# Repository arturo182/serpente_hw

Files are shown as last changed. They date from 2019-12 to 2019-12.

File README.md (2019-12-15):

# Serpente

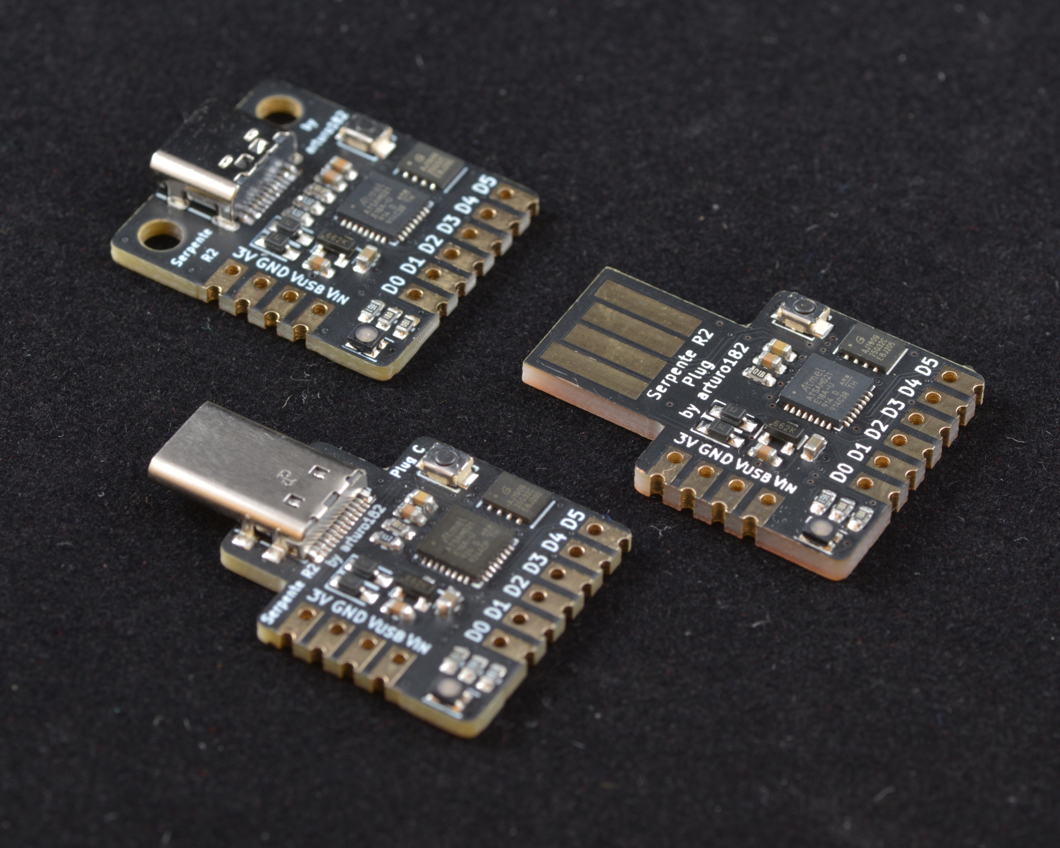
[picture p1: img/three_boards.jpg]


A tiny and cheap CircuitPython development board, perfect for quick projects and prototyping!

Comes in three versions: Female USB Type-C, Male USB Type-C, and bare PCB USB A plug.

# Technical details

- ATSAMD21E18A 32-bit Cortex-M0+ running at 48MHz
- 256KB flash and 32KB RAM
- 4MB Flash for storing files and CircuitPython code
- 6 highly customizable GPIOs
- 250mA LDO
- 3.3V logic and power
- Powered either from USB or external source
- User-controlled RGB LED
- Breadboardable headers
- Castellated edges, can be used as a module
- Mounting holes on the Female Type-C board

# Documentation

For more information visit https://serpente.solder.party/

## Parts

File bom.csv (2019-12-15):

Reference | Quantity | Value | Footprint | Datasheet | LCSC
C2 | 1 | 0.1uF | Capacitor_SMD:C_0603_1608Metric | ~
C3 | 1 | 10uF | Capacitor_SMD:C_0603_1608Metric | ~
C4 C1 | 2 | 1uF | Capacitor_SMD:C_0603_1608Metric | ~
D1 D2 | 2 | D_Schottky_Small | Diode_SMD:D_SOD-323_HandSoldering | ~ | C114023
D3 | 1 | LED_RBAG | LED_SMD:LED_Cree-PLCC4_2x2mm_CW | ~ | C108793
J1 | 1 | USB_C_Receptacle_USB2.0 | Connector_USB_Extra:USB_C_Receptacle_GT-USB-7010 | https://www.usb.org/sites/default/files/documents/usb_type-c.zip | C319148
J2 | 1 | Conn_Power | Connector_PinHeader_2.54mm_Extra:PinHeader_1x04_P2.54mm_Vertical_Castellated | ~
J3 | 1 | Conn_GPIO | Connector_PinHeader_2.54mm_Extra:PinHeader_1x06_P2.54mm_Vertical_Castellated | ~
R1 | 1 | 360R | Resistor_SMD:R_0603_1608Metric | ~
R2 R3 | 2 | 150R | Resistor_SMD:R_0603_1608Metric | ~
R4 R5 | 2 | 5.1K | Resistor_SMD:R_0603_1608Metric | ~
R6 | 1 | 1K | Resistor_SMD:R_0603_1608Metric | ~
SW1 | 1 | SW_RESET | Button_Switch_SMD:SW_SPST_B3U-1000P-B | ~ | C128937
TP1 | 1 | TP_SWCLK | TestPoint:TestPoint_Pad_D1.0mm | ~
TP2 | 1 | TP_SWDIO | TestPoint:TestPoint_Pad_D1.0mm | ~
TP3 | 1 | TP_VDD | TestPoint:TestPoint_Pad_D1.0mm | ~
TP4 | 1 | TP_GND | TestPoint:TestPoint_Pad_D1.0mm | ~
TP5 | 1 | TP_USB_D- | TestPoint:TestPoint_Pad_D1.0mm | ~
TP6 | 1 | TP_USB_D+ | TestPoint:TestPoint_Pad_D1.0mm | ~
TP7 | 1 | TP_RESET | TestPoint:TestPoint_Pad_D1.0mm | ~
U1 | 1 | GD25Q32CNIGR | Package_SON_Extra:USON-8_3x4mm_P0.8mm
U2 | 1 | MCP1700-3302E_SOT23 | Package_TO_SOT_SMD:SOT-23 | http://ww1.microchip.com/downloads/en/DeviceDoc/20001826D.pdf | C83932
U3 | 1 | ATSAMD21E18A | Package_DFN_QFN:QFN-32-1EP_5x5mm_P0.5mm_EP3.6x3.6mm

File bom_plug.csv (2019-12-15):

Reference | Quantity | Value | Footprint | Datasheet
C2 | 1 | 0.1uF | Capacitor_SMD:C_0603_1608Metric | ~
C3 | 1 | 10uF | Capacitor_SMD:C_0603_1608Metric | ~
C4 C1 | 2 | 1uF | Capacitor_SMD:C_0603_1608Metric | ~
D2 D1 | 2 | D_Schottky_Small | Diode_SMD:D_SOD-323_HandSoldering | ~
D3 | 1 | LED_RBAG | LED_SMD:LED_Cree-PLCC4_2x2mm_CW | ~
J1 | 1 | USB_A | Connector_USB_Extra:USB_A_Plug_PCB | ~
J2 | 1 | Conn_Power | Connector_PinHeader_2.54mm_Extra:PinHeader_1x04_P2.54mm_Vertical_Castellated | ~
J3 | 1 | Conn_GPIO | Connector_PinHeader_2.54mm_Extra:PinHeader_1x06_P2.54mm_Vertical_Castellated | ~
R1 | 1 | 360R | Resistor_SMD:R_0603_1608Metric | ~
R3 R2 | 2 | 150R | Resistor_SMD:R_0603_1608Metric | ~
R6 | 1 | 1K | Resistor_SMD:R_0603_1608Metric | ~
SW1 | 1 | SW_RESET | Button_Switch_SMD:SW_SPST_B3U-1000P-B | ~
TP1 | 1 | TP_SWCLK | TestPoint:TestPoint_Pad_D1.0mm | ~
TP2 | 1 | TP_SWDIO | TestPoint:TestPoint_Pad_D1.0mm | ~
TP3 | 1 | TP_VDD | TestPoint:TestPoint_Pad_D1.0mm | ~
TP4 | 1 | TP_GND | TestPoint:TestPoint_Pad_D1.0mm | ~
TP5 | 1 | TP_USB_D- | TestPoint:TestPoint_Pad_D1.0mm | ~
TP6 | 1 | TP_USB_D+ | TestPoint:TestPoint_Pad_D1.0mm | ~
TP7 | 1 | TP_RESET | TestPoint:TestPoint_Pad_D1.0mm | ~
U1 | 1 | GD25Q32CNIGR | Package_SON_Extra:USON-8_3x4mm_P0.8mm
U2 | 1 | MCP1700-3302E_SOT23 | Package_TO_SOT_SMD:SOT-23 | http://ww1.microchip.com/downloads/en/DeviceDoc/20001826D.pdf
U3 | 1 | ATSAMD21E18A | Package_DFN_QFN:QFN-32-1EP_5x5mm_P0.5mm_EP3.6x3.6mm

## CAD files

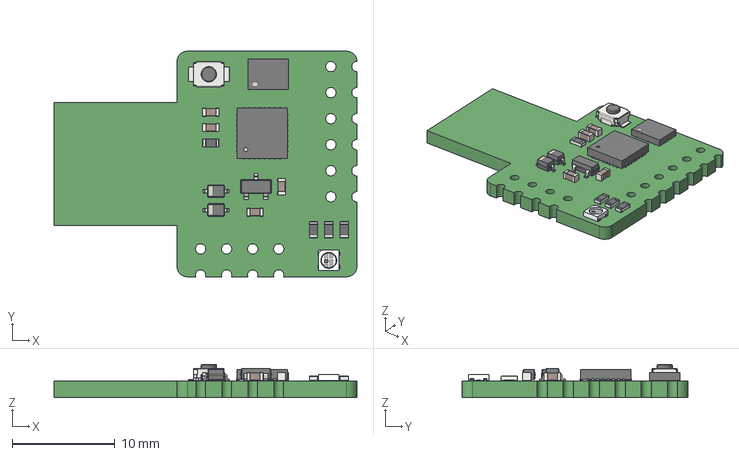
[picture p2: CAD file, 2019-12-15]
serpente_plug.step
29.6 x 22.0 x 3.24 mm

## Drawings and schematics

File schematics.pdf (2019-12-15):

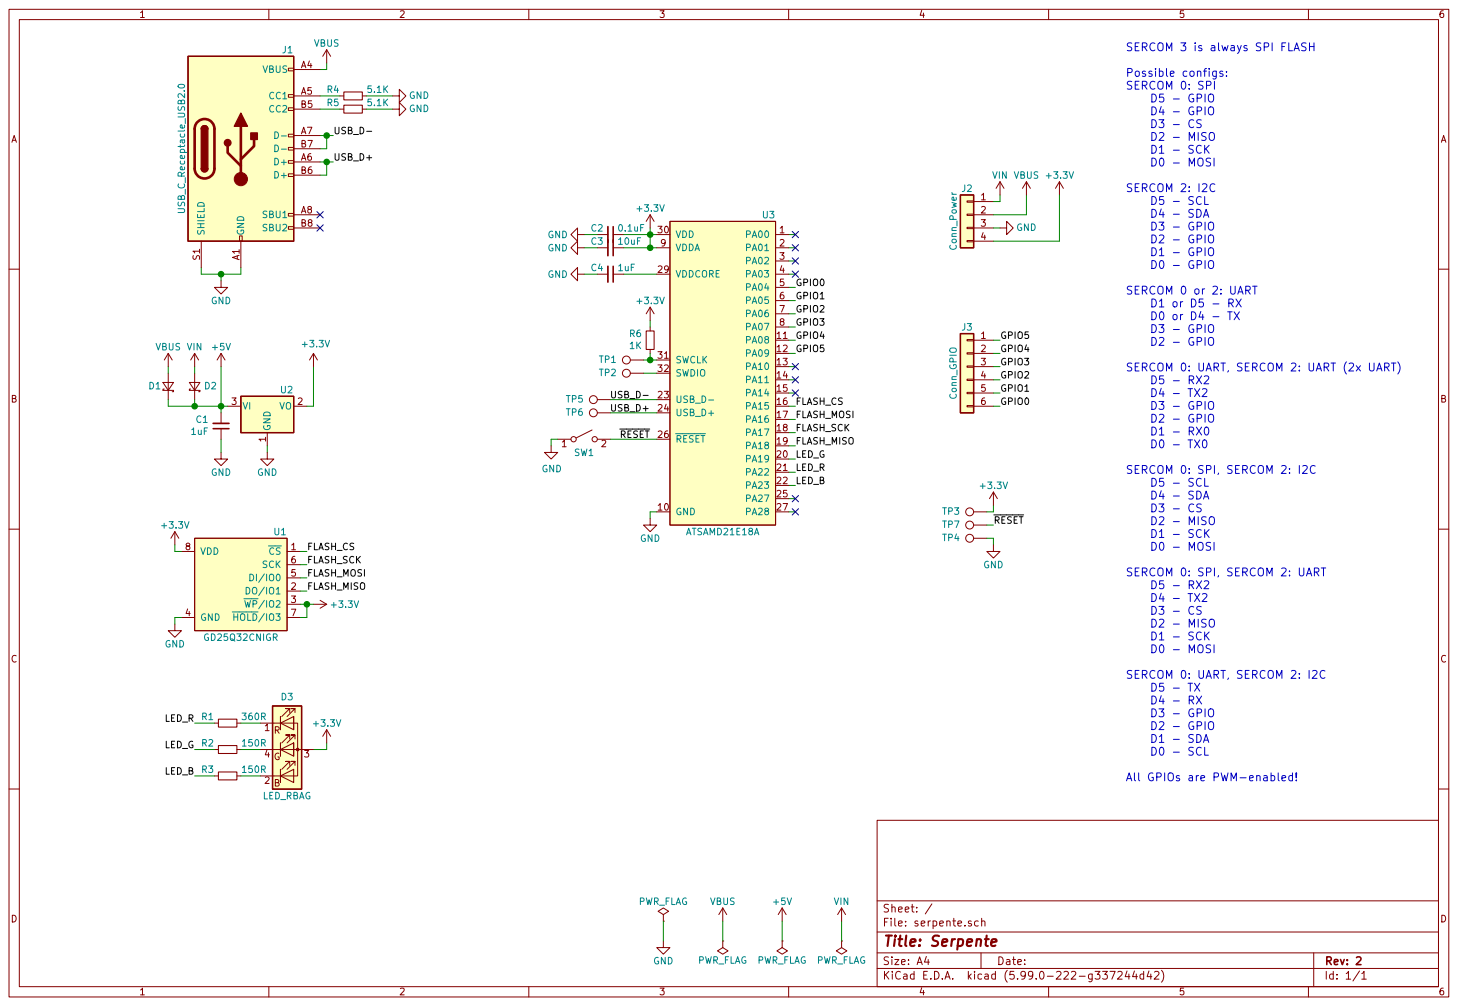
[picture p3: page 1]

All GPIOs are PWM-enabled! +5V

File: serpente.sch Sheet: /
Id: 1/1 Title: Serpente

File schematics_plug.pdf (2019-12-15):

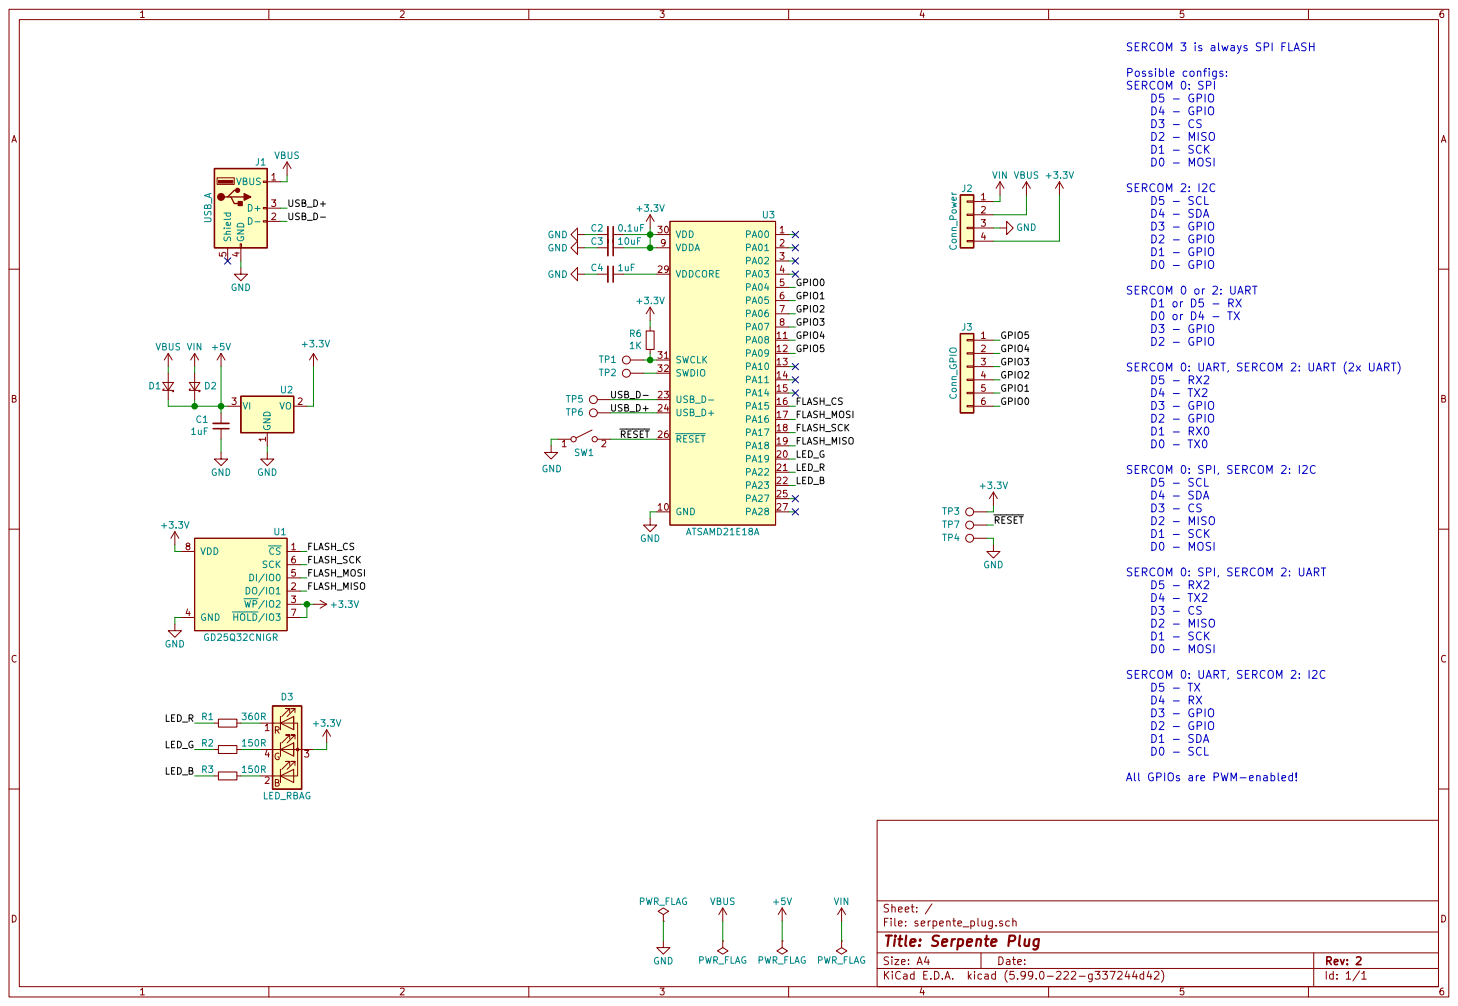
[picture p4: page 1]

SERCOM 3 is always SPI FLASH

File: serpente_plug.sch Sheet: /
Id: 1/1 Title: Serpente Plug

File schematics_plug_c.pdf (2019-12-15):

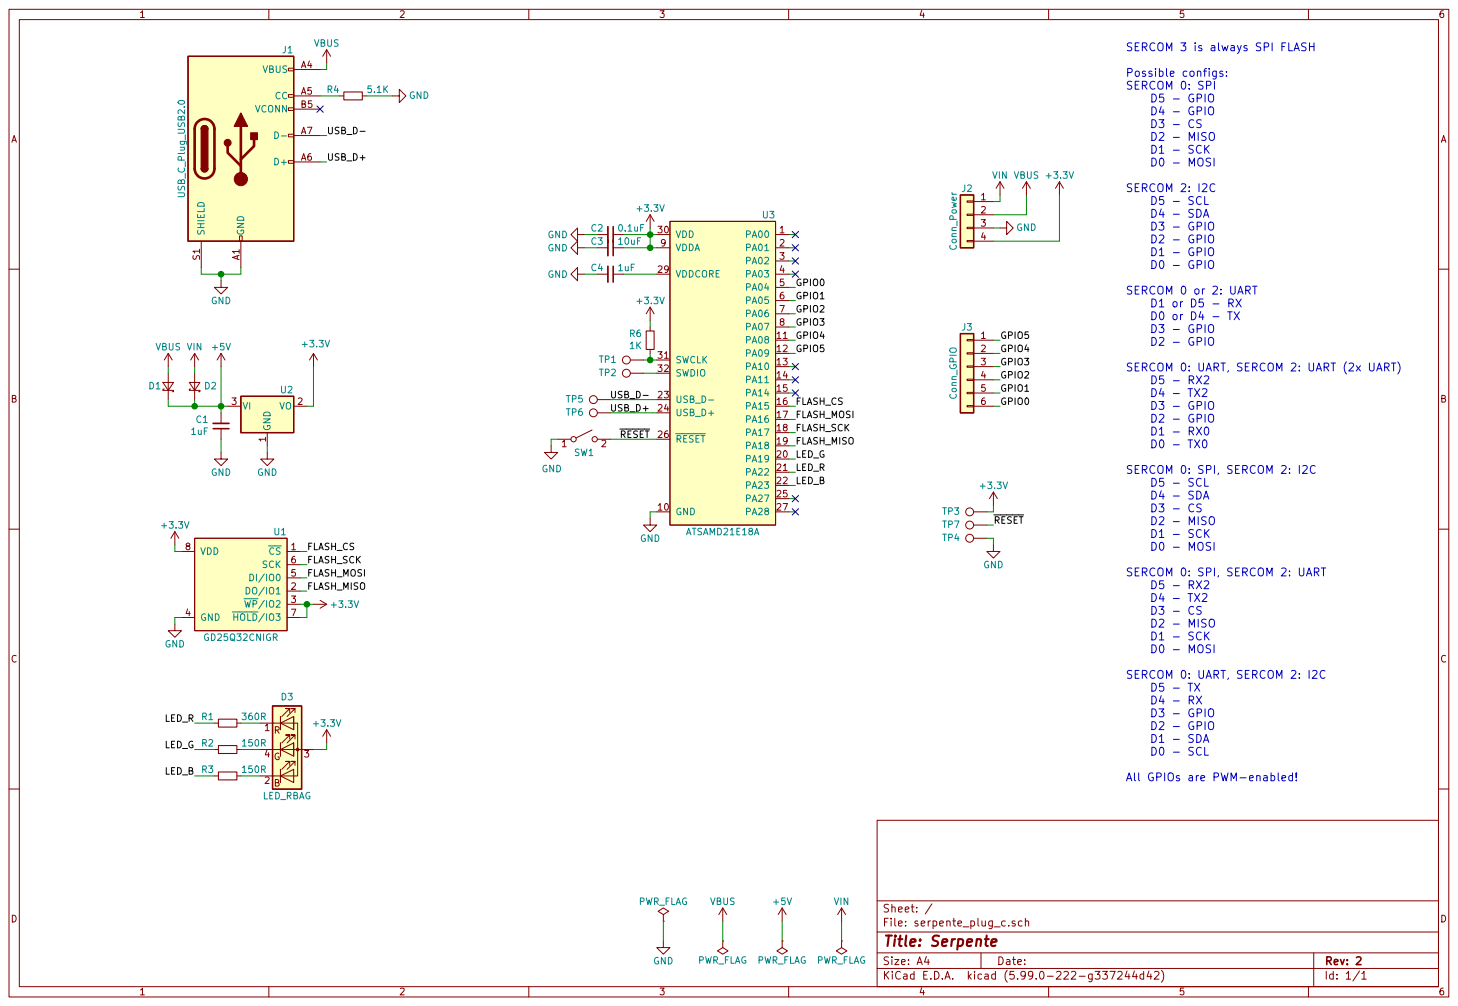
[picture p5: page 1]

All GPIOs are PWM-enabled! +5V

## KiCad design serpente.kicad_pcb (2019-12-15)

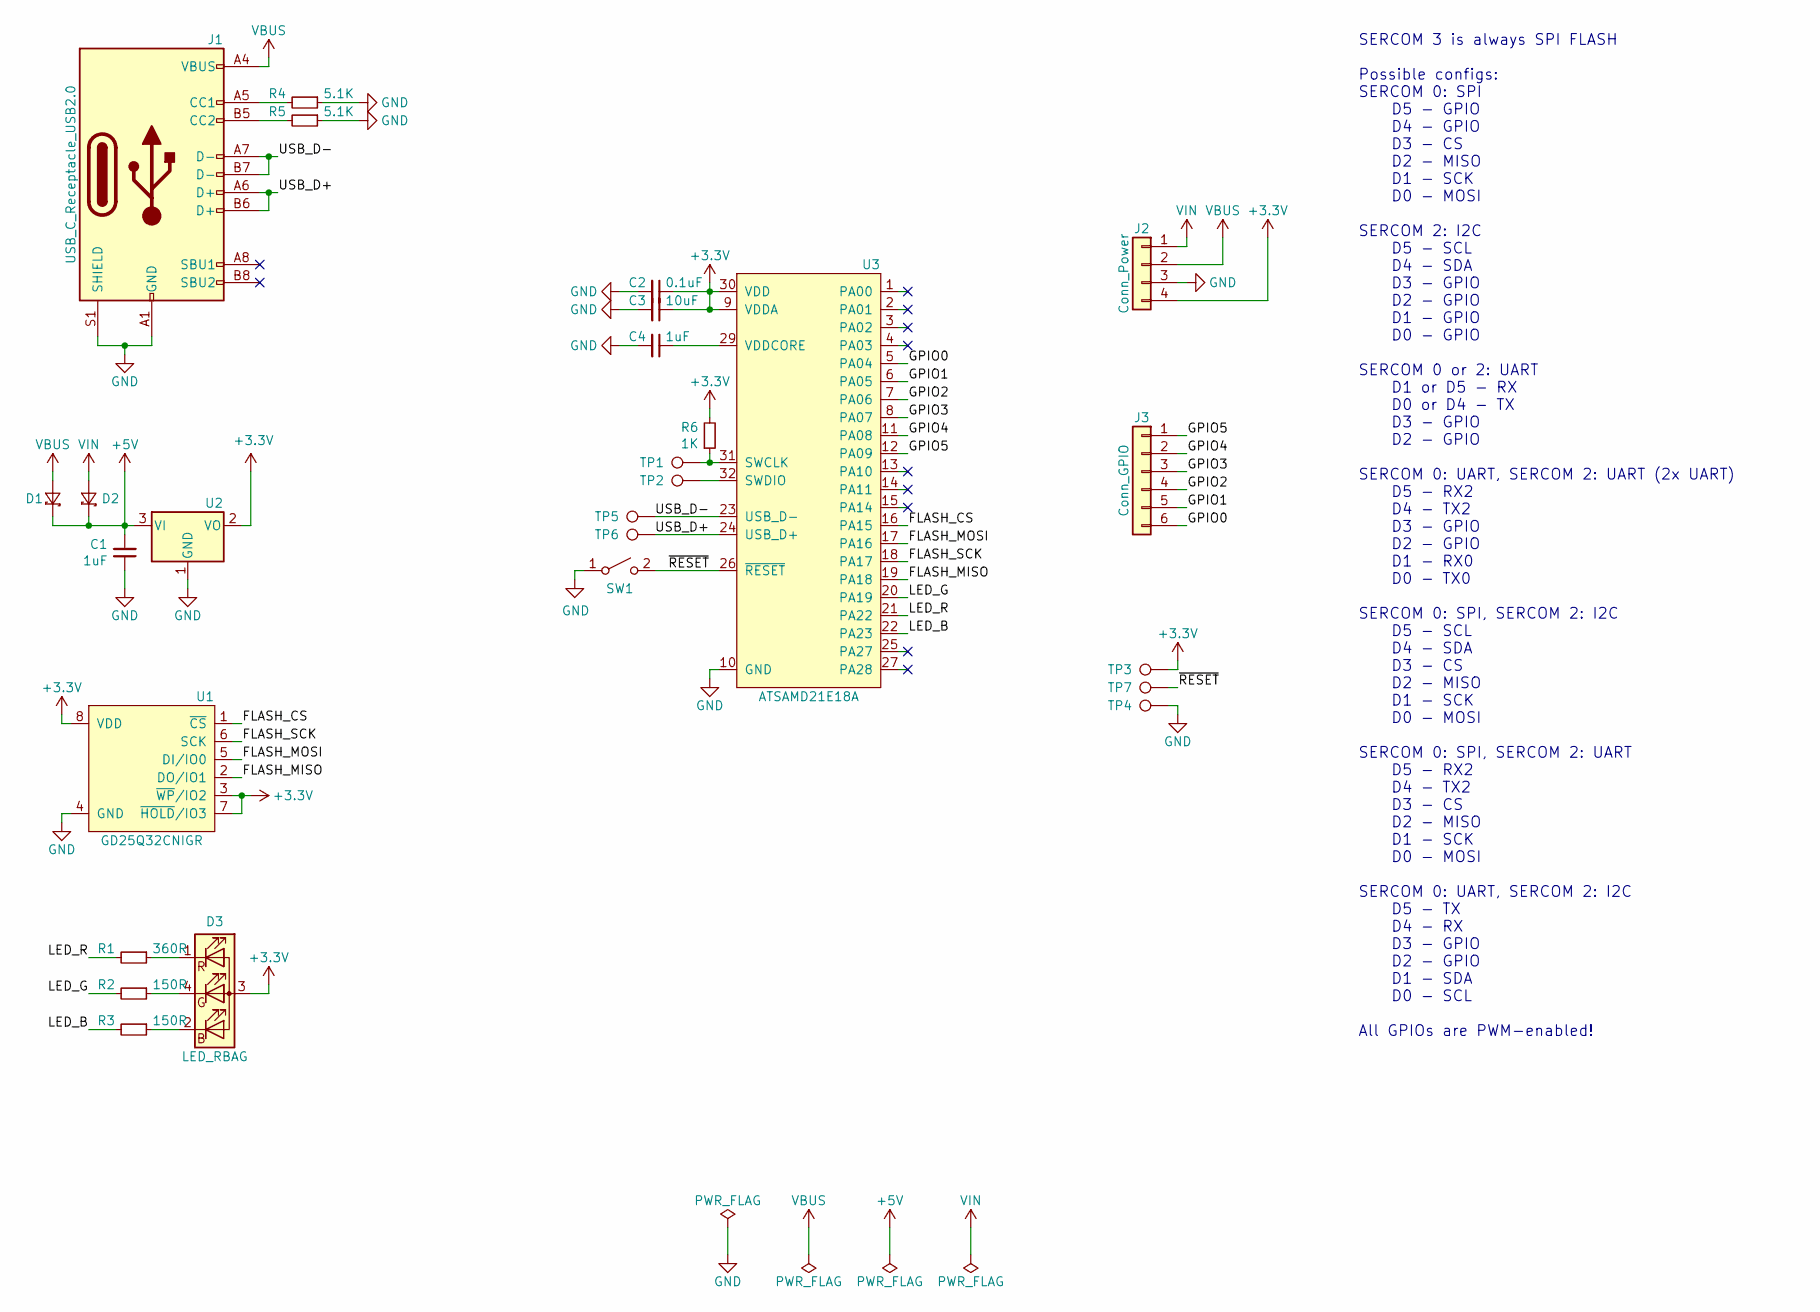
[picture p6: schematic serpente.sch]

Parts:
C1, C4: 1uF; C_0603_1608Metric
C2: 0.1uF; C_0603_1608Metric
C3: 10uF; C_0603_1608Metric
D1, D2: D_Schottky_Small; D_SOD-323_HandSoldering; LCSC C114023
D3: LED_RBAG; LED_Cree-PLCC4_2x2mm_CW; LCSC C108793
J1: USB_C_Receptacle_USB2.0; USB_C_Receptacle_GT-USB-7010; LCSC C319148
J2: Conn_Power; PinHeader_1x04_P2.54mm_Vertical_Castellated
J3: Conn_GPIO; PinHeader_1x06_P2.54mm_Vertical_Castellated
R1: 360R; R_0603_1608Metric
R2, R3: 150R; R_0603_1608Metric
R4, R5: 5.1K; R_0603_1608Metric
R6: 1K; R_0603_1608Metric
SW1: SW_RESET; SW_SPST_B3U-1000P-B; LCSC C128937
TP1: TP_SWCLK; TestPoint_Pad_D1.0mm
TP2: TP_SWDIO; TestPoint_Pad_D1.0mm
TP3: TP_VDD; TestPoint_Pad_D1.0mm
TP4: TP_GND; TestPoint_Pad_D1.0mm
TP5: TP_USB_D-; TestPoint_Pad_D1.0mm
TP6: TP_USB_D+; TestPoint_Pad_D1.0mm
TP7: TP_RESET; TestPoint_Pad_D1.0mm
U1: GD25Q32CNIGR; USON-8_3x4mm_P0.8mm
U2: MCP1700-3302E_SOT23; SOT-23; LCSC C83932
U3: ATSAMD21E18A; QFN-32-1EP_5x5mm_P0.5mm_EP3.6x3.6mm

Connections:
+3V3: C2.1, C3.1, D3.3 (A), J2.4, R6.2, TP3.1, U1.3 (~WP~/IO2), U1.7 (~HOLD~/IO3), U1.8 (VDD), U2.2 (VO), U3.9 (VDDA), U3.30 (VDD)
+5V: C1.2, D1.1 (K), D2.1 (K), U2.3 (VI)
/FLASH_CS: U1.1 (~CS~), U3.16 (PA15)
/FLASH_MISO: U1.2 (DO/IO1), U3.19 (PA18)
/FLASH_MOSI: U1.5 (DI/IO0), U3.17 (PA16)
/FLASH_SCK: U1.6 (SCK), U3.18 (PA17)
/GPIO0: J3.6, U3.5 (PA04)
/GPIO1: J3.5, U3.6 (PA05)
/GPIO2: J3.4, U3.7 (PA06)
/GPIO3: J3.3, U3.8 (PA07)
/GPIO4: J3.2, U3.11 (PA08)
/GPIO5: J3.1, U3.12 (PA09)
/LED_B: R3.2, U3.22 (PA23)
/LED_G: R2.2, U3.20 (PA19)
/LED_R: R1.2, U3.21 (PA22)
/USB_D+: J1.A6 (D+), J1.B6 (D+), TP6.1, U3.24 (USB_D+)
/USB_D-: J1.A7 (D-), J1.B7 (D-), TP5.1, U3.23 (USB_D-)
/~RESET~: SW1.2 (B), TP7.1, U3.26 (~RESET~)
GND: C1.1, C2.2, C3.2, C4.2, J1.A1 (GND), J1.A12 (GND), J1.B1 (GND), J1.B12 (GND), J1.S1 (SHIELD), J2.3, R4.1, R5.1, SW1.1 (A), TP4.1, U1.4 (GND), U2.1 (GND), U3.10 (GND), U3.28 (GND)
unnamed: C4.1, U3.29 (VDDCORE)
unnamed: D3.1 (RK), R1.1
unnamed: D3.2 (BK), R3.1
unnamed: D3.4 (GK), R2.1
unnamed: J1.A5 (CC1), R4.2
unnamed: J1.B5 (CC2), R5.2
unnamed: R6.1, TP1.1, U3.31 (SWCLK)
unnamed: TP2.1, U3.32 (SWDIO)
VBUS: D1.2 (A), J1.A4 (VBUS), J1.A9 (VBUS), J1.B4 (VBUS), J1.B9 (VBUS), J2.2
VIN: D2.2 (A), J2.1

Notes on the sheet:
SERCOM 3 is always SPI FLASH Possible configs: SERCOM 0: SPI D5 - GPIO D4 - GPIO D3 - CS D2 - MISO D1 - SCK D0 - MOSI SERCOM 2: I2C D5 - SCL D4 - SDA D3 - GPIO D2 - GPIO D1 - GPIO D0 - GPIO SERCOM 0 or 2: UART D1 or D5 - RX D0 or D4 - TX D3 - GPIO D2 - GPIO SERCOM 0: UART, SERCOM 2: UART (2x UART) 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

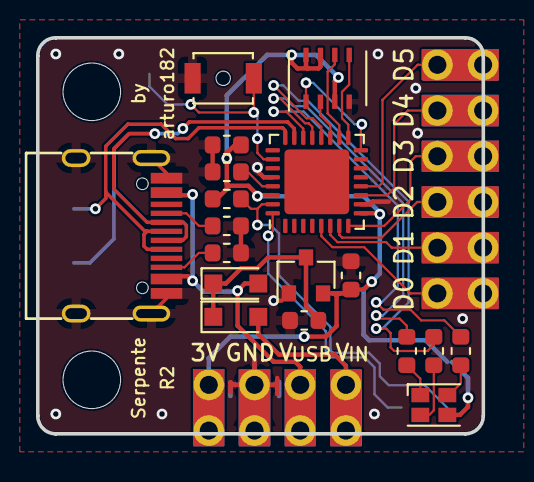
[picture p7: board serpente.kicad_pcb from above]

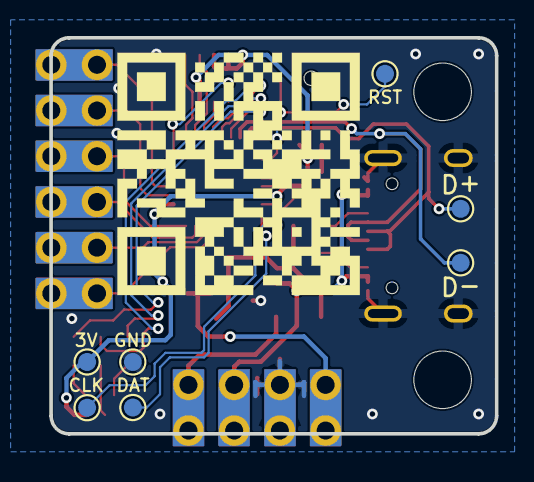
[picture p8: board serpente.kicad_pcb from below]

Board: 2 copper layers, 24.8 x 22.0 mm, 27 parts (7 on the bottom side), 29 nets.

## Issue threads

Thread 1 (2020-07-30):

Opening project in KiCad 5.1.6 issues and DRC

alborzs, 2020-07-30:
Hi,
I stumbled upon your project and would love to use it in one of my hobby project, unfortunately I can't use the castellated version as I have some dimension requirements specially in depth.
I was hoping to open your project in KiCad and do the PCB myself but that did not really work. It is complaining about the KiCad version. So instead I started from scratch and tried to add the necessary components from your library and modules repos.
The schematics is fine but generates the following DRC (I have not looked into this yet and just wanted to know if you recognize it)
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

The bigger issue comes when I try to add the components in PCBnew, it is complaining with the following error:

- Error: J1 pad B1 not found in Connector_USB_Extra:USB_C_Plug_UTC009-C12.
- Error: J1 pad A12 not found in Connector_USB_Extra:USB_C_Plug_UTC009-C12.
- Error: J1 pad A9 not found in Connector_USB_Extra:USB_C_Plug_UTC009-C12.
- Error: J1 pad B4 not found in Connector_USB_Extra:USB_C_Plug_UTC009-C12.

The component is imported as shown below in KiCad:
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

But I would like to know how you managed to get around this issue.
Thanks and great little boards by the way.

arturo182, 2020-07-30:
Hi alborzs,

Sorry about the file problems, I use KiCad nightly builds so they might be incompatible with the stable releases.

You don't have to worry about either problem, not sure why the ERC complains about the types there, the LDO is a power output and the 3.3V is a power input, so even if it complains, that connection is correct.

As for the USB footprint, that's also not a problem, the schematic symbol has extra pins for VBUS and GND (4 for each), which are missing in the footprint, but the other 2 of each signal are there so the connection exists.

Finally, for the component itself, I got them directly from an Alibaba seller here: https://www.alibaba.com/product-detail/High-Quality-12pin-vertical-SMT-Plug_60838073588.html

alborzs, 2020-07-31:
@arturo182, thanks for the reply.

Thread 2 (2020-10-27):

Fast Role Swap?

topherbuckley, 2020-10-27:
When you say:

>Powered either from USB or external source

Does this include the ability to hot swap between them as in meeting the Fast Role Swap USB standard? I'm hoping to design something that plugs into a smartphone and uses the smartphone as a power source until plugged into an external power source without shutting down the microcontroller.

arturo182, 2020-10-27:
Hi,

As you can see in the schematic, the power selection uses diodes to protect from feeding back the voltage to the other source:
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

This means having two sources connected at the same time and then removing one of them should be safe and should not reset the microcontroller.

topherbuckley, 2020-10-28:
Ah ok, so I guess this will not work because of this actually. I was hoping to charge the smartphone (sink) when connected to external power, but this diode configuration would not allow this it seems.

Also it is my understanding that a simple switch will not swap the roles from source to sink, and a Power Delivery controller is necessary.

Curious though, have you tried communicating with an Android phone with these? I may still have an alternate use for them if so.

arturo182, 2020-10-28:
Yes, I used the Type-C Plug with my phone and the board shows up as a hardware keyboard so you can send keys to your phone and I believe there's more you can do with CircuitPython and Apple devices via USB but I haven't tried that, more details here: https://learn.adafruit.com/use-circuitpython-devices-with-iphone-ipad?view=all

topherbuckley, 2020-10-28:
Cool! I see some use cases on android for CircuitPython as well. I'll likely pick up a few of these to fiddle with then. Who knows, maybe add a Power Delivery circuit at some point too!

Closed 2020-10-28.

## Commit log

2019-08-17 Initial import, WIP
    [serpente.kicad_pcb, serpente.sch]
2019-08-17 Add readme and fix text error in schematic
    [serpente.sch]
2019-08-18 Rev 1
    [serpente.kicad_pcb, serpente.sch]
2019-08-18 Add Plug variant, make header positions same between variants
    [serpente.kicad_pcb, serpente_plug.kicad_pcb, serpente_plug.sch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]
2019-09-04 Fix GPIO numbers, add BOM, update README
    [bom.csv, bom_plug.csv, serpente.kicad_pcb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]
2019-12-15 Final rev 2 release!
    [bom.csv, bom_plug.csv, bom_plug_c.csv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]
